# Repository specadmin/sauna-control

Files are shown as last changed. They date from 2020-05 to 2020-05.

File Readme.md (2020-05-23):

# Sauna control #

This is a control board for the sauna equipment. It includes thermostat and recycling motor control.

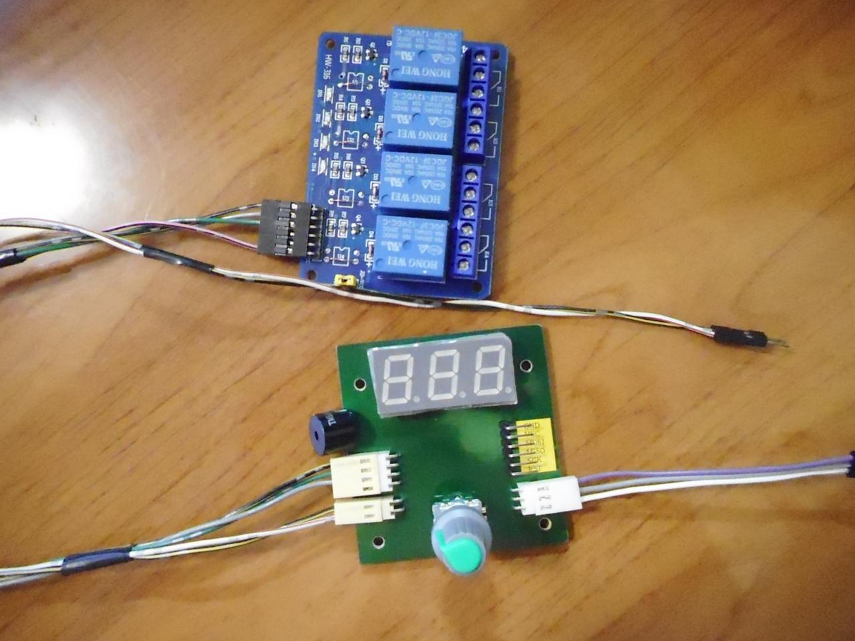
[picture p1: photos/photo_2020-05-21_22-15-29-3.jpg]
Result view


| Front side assembly | Back side assembly |
|---|---|
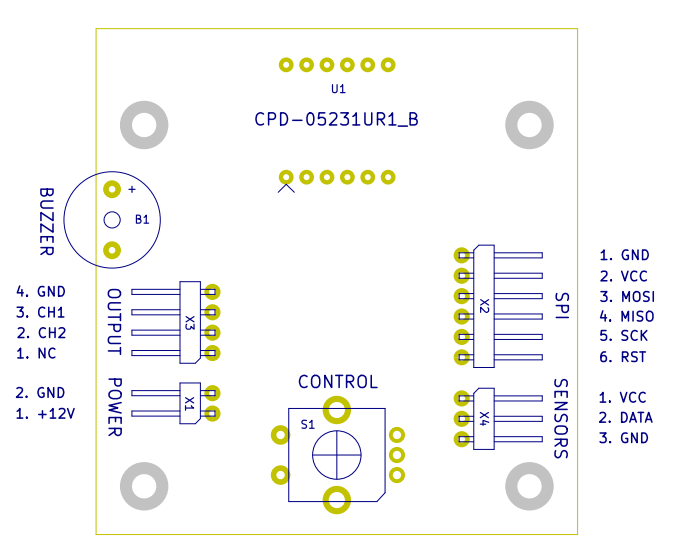
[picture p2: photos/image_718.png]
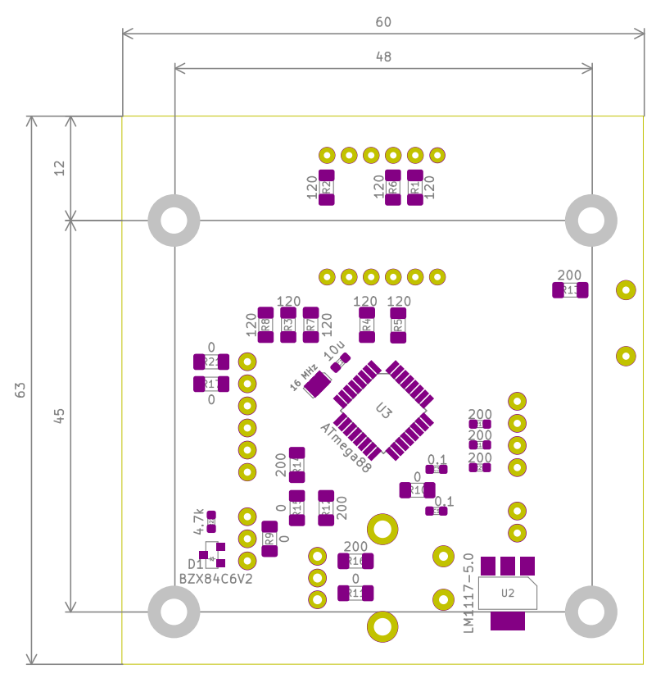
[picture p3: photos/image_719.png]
|  |  |

## Get sources ##

```
git clone https://github.com/specadmin/sauna-control
cd sauna-control
git submodule update --init
```

## Compile  ##

`make`

Make sure you have `avr-gcc` and `avr-libc` installed before running this command.

## Upload ##

`make install`

This command uses `avrdude` for uploading the firmware. See Makefile for details.

## Code modification ##

Use Code::Blocks or any other IDE for code modification.

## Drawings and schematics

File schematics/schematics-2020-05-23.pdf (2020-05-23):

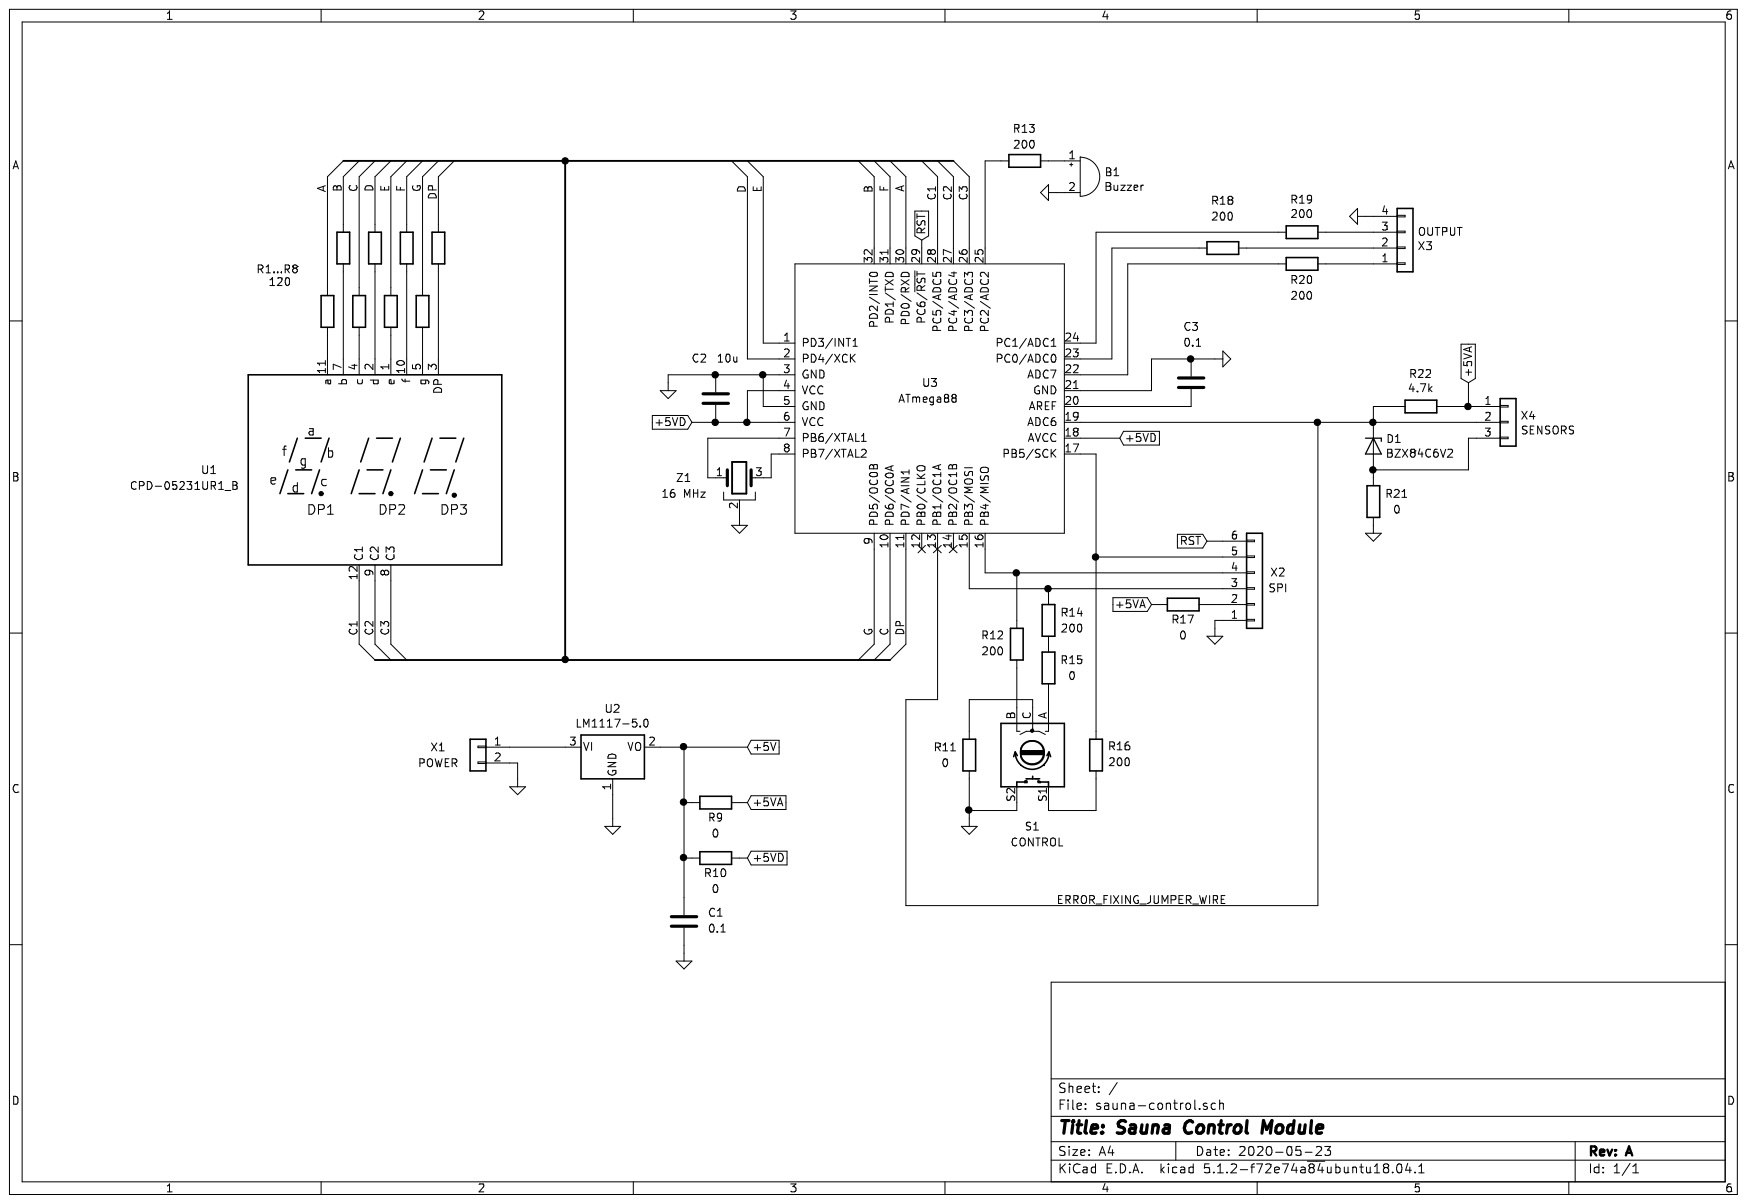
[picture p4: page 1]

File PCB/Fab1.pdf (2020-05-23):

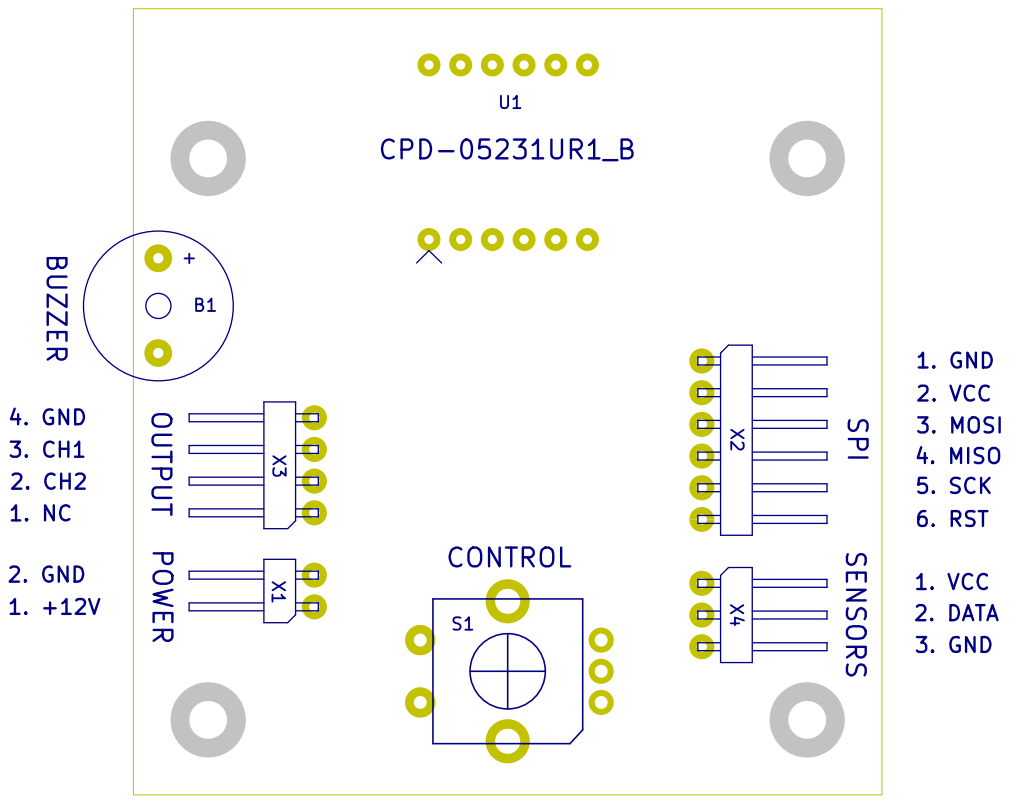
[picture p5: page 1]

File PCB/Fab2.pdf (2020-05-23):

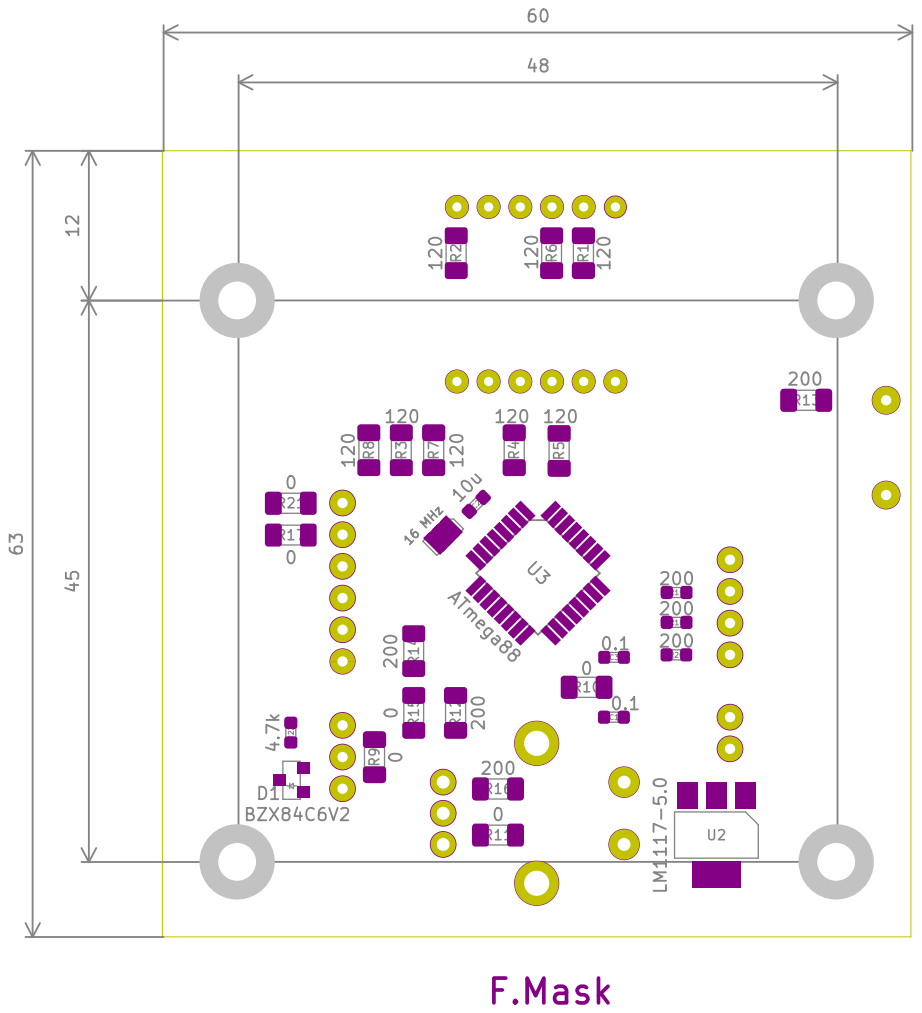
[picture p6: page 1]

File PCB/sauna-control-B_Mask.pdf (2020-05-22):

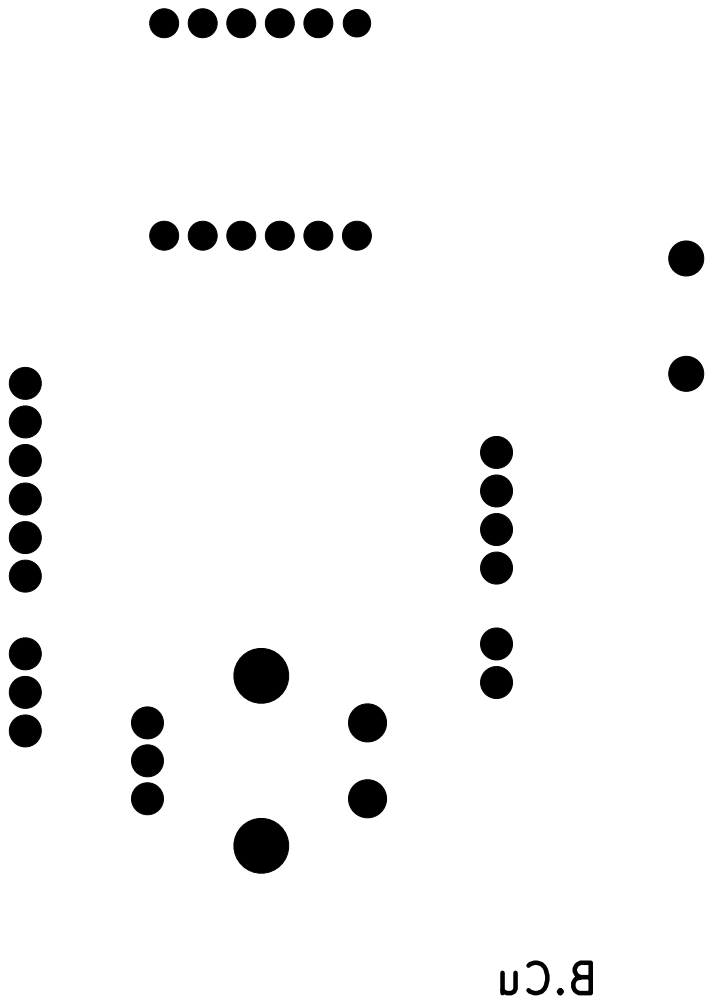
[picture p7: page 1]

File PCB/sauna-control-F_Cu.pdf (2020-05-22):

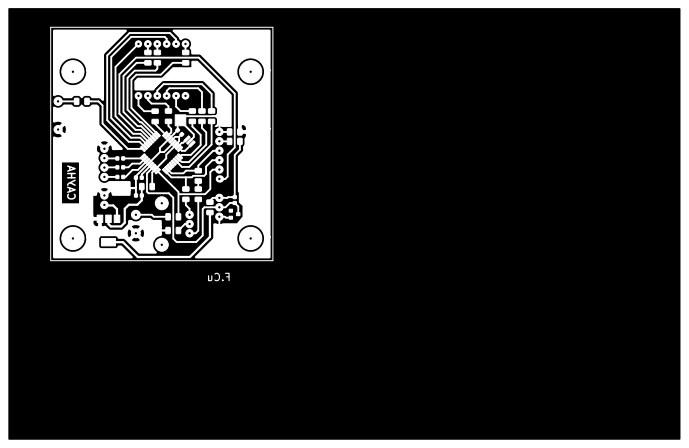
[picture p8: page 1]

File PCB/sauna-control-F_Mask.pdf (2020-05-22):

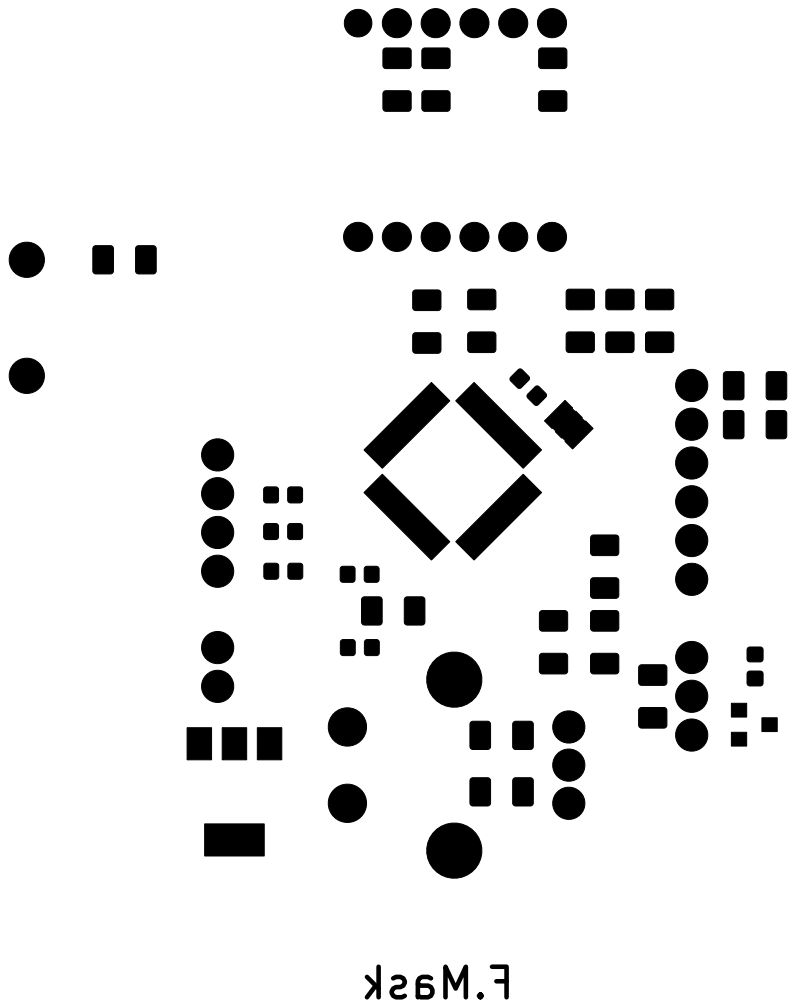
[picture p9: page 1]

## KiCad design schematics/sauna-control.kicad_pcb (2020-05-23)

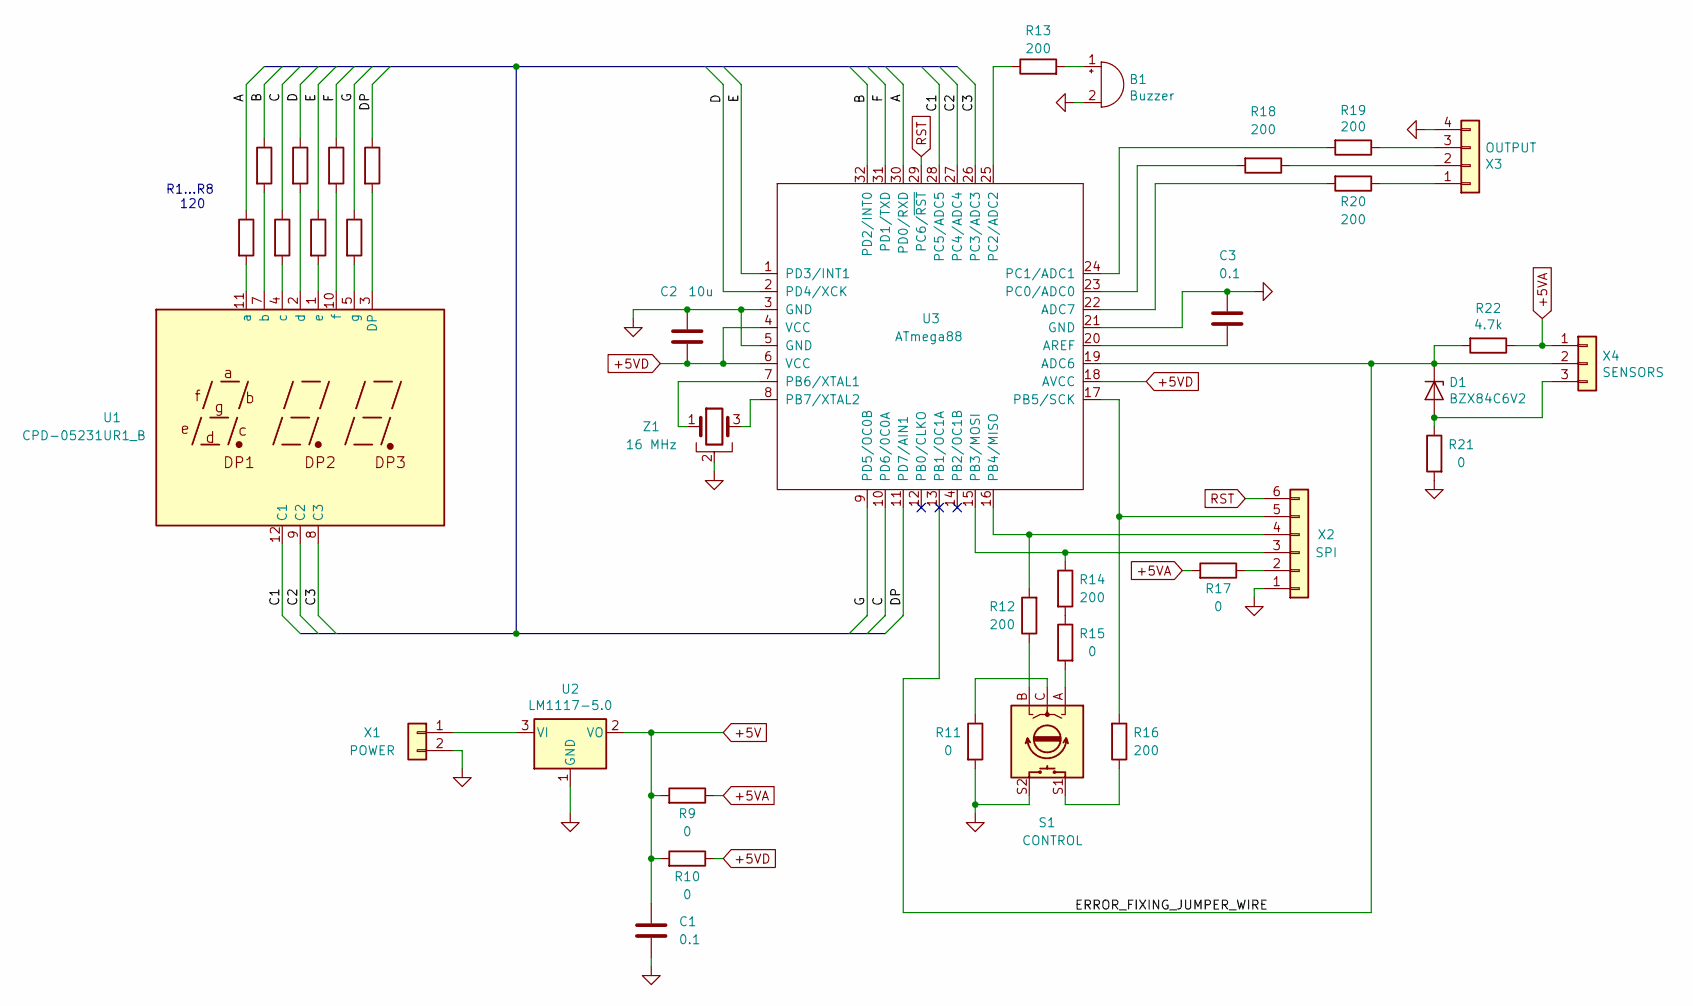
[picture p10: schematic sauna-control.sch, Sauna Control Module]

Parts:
B1: Buzzer; Buzzer_12x9.5RM7.6
C1, C3: 0.1; C_0603_1608Metric
C2: 10u; C_0603_1608Metric
D1: BZX84C6V2; D_SOT-23_ANK
R1, R2, R3, R4, R5, R6, R7, R8: 120; R_1206_3216Metric
R9, R10, R11, R15, R17, R21: 0; R_1206_3216Metric
R12, R13, R14, R16: 200; R_1206_3216Metric
R18, R19, R20: 200; R_0603_1608Metric
R22: 4.7k; R_0603_1608Metric
S1: CONTROL; RotaryEncoder_Alps_EC11E-Switch_Vertical_H20mm_CircularMoun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
U1: CPD-05231UR1_B; CPD-05231UR1B
U2: LM1117-5.0; SOT-223-3_TabPin2
U3: ATmega88; TQFP-32_7x7mm_P0.8mm
X1: POWER; PinHeader_1x02_P2.54mm_Horizontal
X2: SPI; PinHeader_1x06_P2.54mm_Horizontal
X3: OUTPUT; PinHeader_1x04_P2.54mm_Horizontal
X4: SENSORS; PinHeader_1x03_P2.54mm_Horizontal
Z1: 16 MHz; Resonator_SMD_muRata_CSTxExxV-3Pin_3.0x1.1mm

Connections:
+5V: C1.2, R9.2, R10.2, U2.2 (VO)
+5VA: R9.1, R17.2, R22.1, X4.1
+5VD: C2.1, R10.1, U3.4 (VCC), U3.6 (VCC), U3.18 (AVCC)
/A: R1.1, U3.30 (PD0/RXD)
/B: R2.1, U3.32 (PD2/INT0)
/C: R3.1, U3.10 (PD6/0C0A)
/C1: U1.12 (C1), U3.28 (PC5/ADC5)
/C2: U1.9 (C2), U3.27 (PC4/ADC4)
/C3: U1.8 (C3), U3.26 (PC3/ADC3)
/D: R4.1, U3.2 (PD4/XCK)
/DP: R8.1, U3.11 (PD7/AIN1)
/E: R5.1, U3.1 (PD3/INT1)
/ERROR_FIXING_JUMPER_WIRE: D1.1 (K), R22.2, U3.13 (PB1/OC1A), U3.19 (ADC6), X4.2
/F: R6.1, U3.31 (PD1/TXD)
/G: R7.1, U3.9 (PD5/OC0B)
GND: B1.2 (+), C1.1, C2.2, C3.2, R11.2, R21.2, S1.S2, U2.1 (GND), U3.3 (GND), U3.5 (GND), U3.21 (GND), X1.2, X2.1, X3.4, Z1.2
unnamed: B1.1 (-), R13.2
unnamed: C3.1, U3.20 (AREF)
unnamed: D1.2 (A), R21.1, X4.3
unnamed: R1.2, U1.11 (a)
unnamed: R2.2, U1.7 (b)
unnamed: R3.2, U1.4 (c)
unnamed: R4.2, U1.2 (d)
unnamed: R5.2, U1.1 (e)
unnamed: R6.2, U1.10 (f)
unnamed: R7.2, U1.5 (g)
unnamed: R8.2, U1.3 (DP)
unnamed: R11.1, S1.C
unnamed: R12.1, S1.B
unnamed: R12.2, U3.16 (PB4/MISO), X2.4
unnamed: R13.1, U3.25 (PC2/ADC2)
unnamed: R14.1, U3.15 (PB3/MOSI), X2.3
unnamed: R14.2, R15.1
unnamed: R15.2, S1.A
unnamed: R16.1, S1.S1
unnamed: R16.2, U3.17 (PB5/SCK), X2.5
unnamed: R17.1, X2.2
unnamed: R18.1, X3.2
unnamed: R18.2, U3.23 (PC0/ADC0)
unnamed: R19.1, X3.3
unnamed: R19.2, U3.24 (PC1/ADC1)
unnamed: R20.1, X3.1
unnamed: R20.2, U3.22 (ADC7)
unnamed: U2.3 (VI), X1.1
unnamed: U3.7 (PB6/XTAL1), Z1.1
unnamed: U3.8 (PB7/XTAL2), Z1.3
RST: U3.29 (PC6/~RST), X2.6

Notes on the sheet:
R1...R8 120

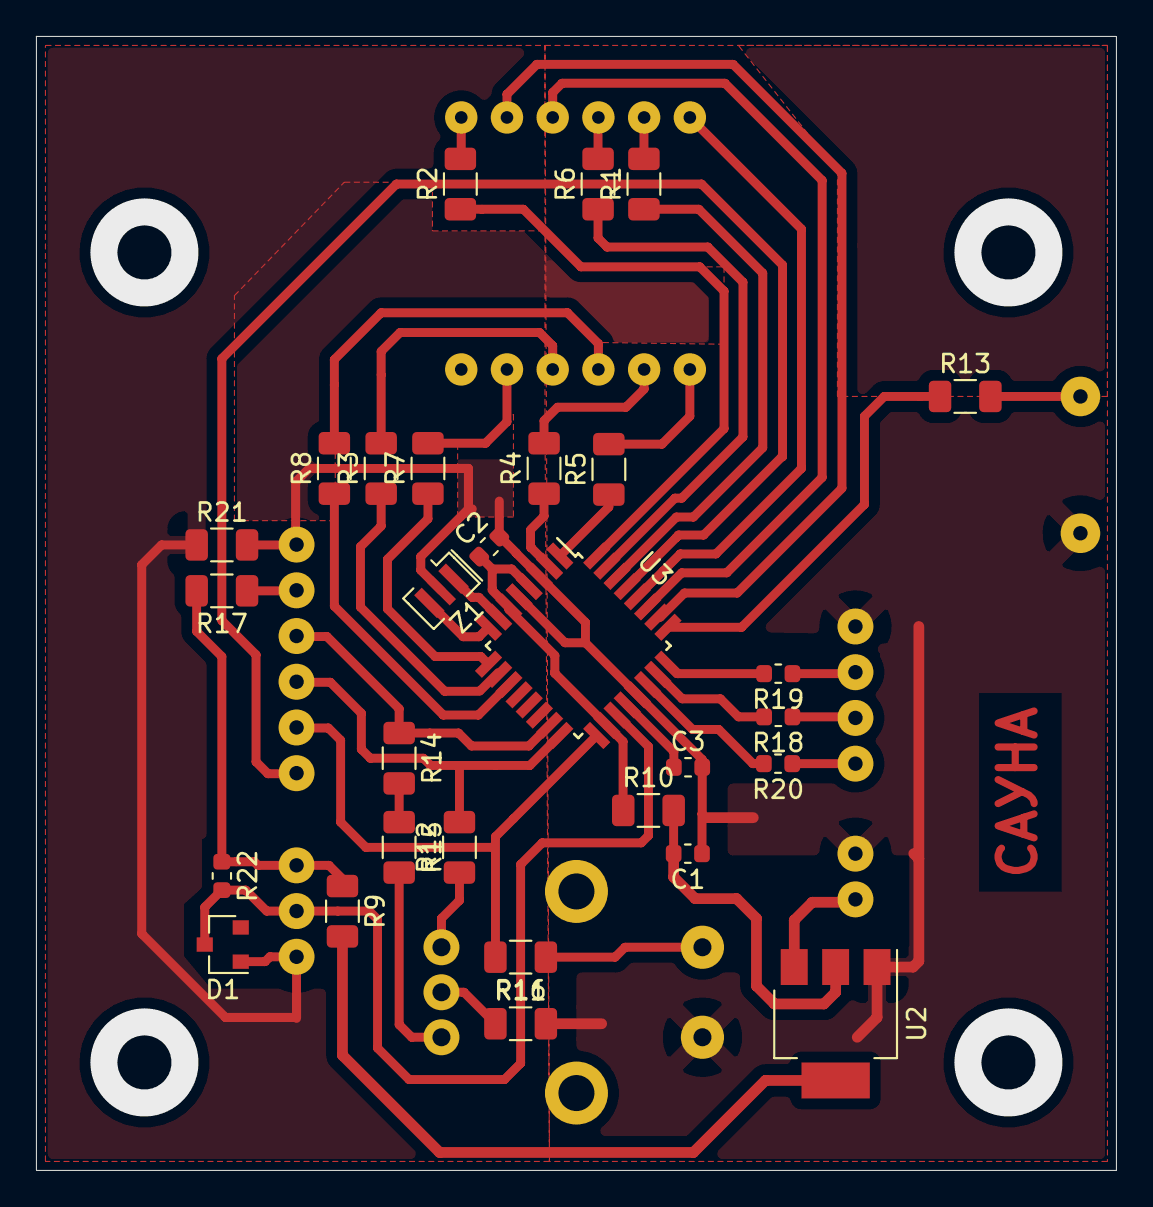
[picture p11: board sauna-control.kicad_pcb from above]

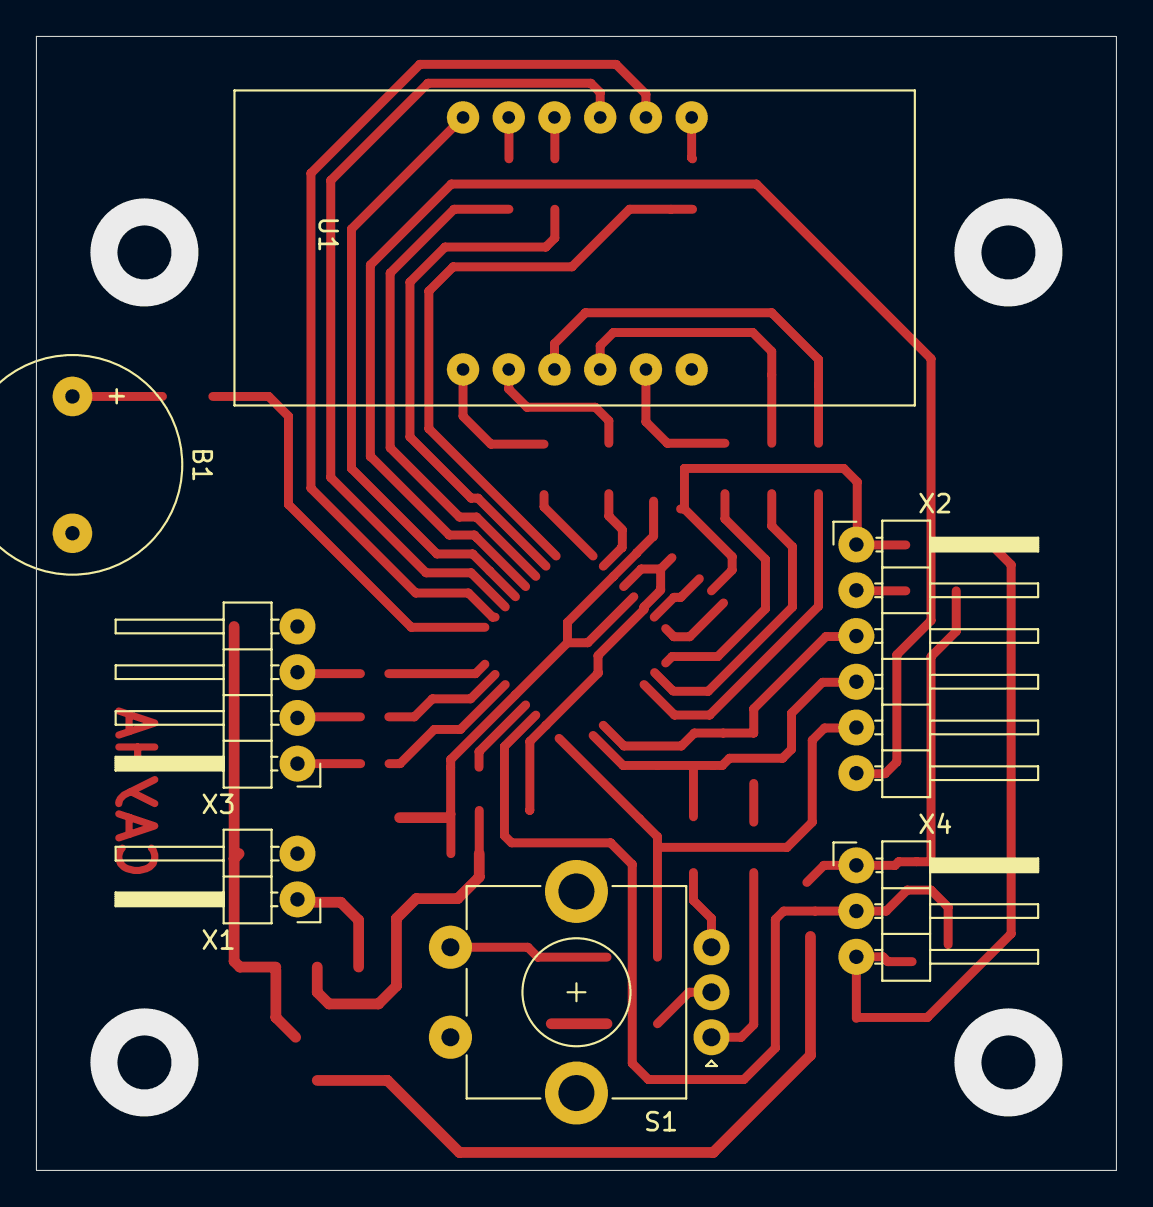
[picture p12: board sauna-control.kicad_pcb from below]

Board: 2 copper layers, 60.0 x 63.0 mm, 36 parts (7 on the bottom side), 47 nets.

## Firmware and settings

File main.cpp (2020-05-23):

//-----------------------------------------------------------------------------
#include "lib/avr-misc/avr-misc.h"
#include "lib/avr-debug/debug.h"
#include "lib/DS1820/DS1820.h"
#include "disp7seg.h"
#include "config.h"
//-----------------------------------------------------------------------------
#ifdef BEEPER_PORT
    #define beep(ms)       { set_bit(BEEPER_PORT, BEEPER_BIT); mdelay(ms); clr_bit(BEEPER_PORT, BEEPER_BIT); }
#else
    #define beep(ms)
#endif
#define enable_timer()      TCCR0B = 0x04;
#define disable_timer()     TCCR0B = 0x00;
#define enable_encoder()    set_bit(PCMSK0, PCINT3);
#define disable_encoder()   clr_bit(PCMSK0, PCINT3);
#define button_pushed()     (!test_bit(BUTTON_PIN, BUTTON_BIT))
//-----------------------------------------------------------------------------
enum
{
    MODE_SLEEP,
    MODE_SET,
    MODE_STABILIZE,
    MODE_CONFIG,
    MODE_ERROR
};
//-----------------------------------------------------------------------------
enum controlChannel
{
    HEATER,
    BLOWER
};
//-----------------------------------------------------------------------------
BYTE            mode                = MODE_SLEEP;
WORD            mode_time           = 0;
WORD            button_pushed_time  = 0;
BYTE            target_temp;
BYTE            top_temp;
BYTE            bottom_temp;
bool            bottom_sensor_enabled;
BusDS1820       bus;
SensorDS1820*   top_sensor          = NULL;
SensorDS1820*   bottom_sensor       = NULL;
Display7Seg     display(3);
EEBYTE          saved_target_temp;
EEQWORD         saved_top_address;
EEQWORD         saved_bottom_address;
//-----------------------------------------------------------------------------
void turn_on(controlChannel channel)
{
    set_bit(PORTC, channel);
}
//-----------------------------------------------------------------------------
void turn_off(controlChannel channel)
{
    clr_bit(PORTC, channel);
}
//-----------------------------------------------------------------------------
void throwError(BYTE error_code)
{
    // turn off everything
    turn_off(HEATER);
    turn_off(BLOWER);

    // display error code
    char* buf = toHexString(error_code);
    display.print(buf);
    display.hideDot();
    free(buf);

    mode = MODE_ERROR;

    // disable encoder rotations
    disable_encoder();

    // clear pending interrupts flags
    PCIFR = 1;
}
//-----------------------------------------------------------------------------
__inline BYTE init_sensors()
{
    if(!bus.searchDevices())
    {
        return 0xE1;
    }

    QWORD tmp64;
    if(!top_sensor)
    {
        tmp64 = saved_top_address;
        top_sensor = new SensorDS1820(tmp64);
    }

    if(!top_sensor->available())
    {
        return 0xE4;
    }

    tmp64 = saved_bottom_address;
    if(tmp64)
    {
        if(!bottom_sensor)
        {
            bottom_sensor = new SensorDS1820(tmp64);
        }
        bottom_sensor_enabled = true;
        if(!bottom_sensor->available())
        {
            return 0xE5;
        }
    }
    else
    {
        bottom_sensor_enabled = false;
    }

    return 0;
}
//-----------------------------------------------------------------------------
void power_on()
{
    BYTE error = init_sensors();
    if(error)
    {
        throwError(error);
    }
    else
    {
        beep(150);
        target_temp = saved_target_temp;
        if(target_temp < MIN_TEMP || target_temp > MAX_TEMP)
        {
            target_temp = MIN_TEMP;
        }
        display.print(target_temp);
        enable_encoder();
        mode = MODE_SET;
        mode_time = 0;
    }
    enable_timer();
}
//-----------------------------------------------------------------------------
void power_off()
{
    disable_timer();
    DISPLAY_PORT = 0;
    display.hideDot();
    turn_off(HEATER);
    turn_off(BLOWER);
    if(saved_target_temp != target_temp)
    {
        saved_target_temp = target_temp;
    }
    beep(300);
    mode = MODE_SLEEP;
}
//-----------------------------------------------------------------------------
void configure_sensors()
{
    mode = MODE_CONFIG;
    display.print("TOP");
    enable_timer(); mdelay(500);
    display.showDot(); mdelay(500);
    display.hideDot(); mdelay(500);
    while(bus.searchDevices() != 1)
    {
        display.showDot(); mdelay(500);
        display.hideDot(); mdelay(500);
    }
    // save top sensor address
    saved_top_address = bus.getFirstDeviceAddress();
    beep(700);

    saved_bottom_address = 0;
    display.print("BOT"); mdelay(500);
    display.showDot(); mdelay(500);
    display.hideDot(); mdelay(500);
    while(bus.searchDevices() != 2)
    {
        display.showDot(); mdelay(500);
        display.hideDot(); mdelay(500);
    }

    // save bottom sensor address
    if(bus.getFirstDeviceAddress() != saved_top_address)
    {
        saved_bottom_address = bus.getFirstDeviceAddress();
    }
    else
    {
        saved_bottom_address = bus.getNextDeviceAddress();
    }
    display.showDot(); mdelay(500);
    display.hideDot(); mdelay(500);
    beep(700);

    power_on();
}
//-----------------------------------------------------------------------------
int main()
{
    DEBUG_INIT();

    // configure ouputs
    DDRD = 0xFF;
    DDRC = 0x3F;

    // configure buttons
    set_bit(ENCODER_A_PORT, ENCODER_A_BIT);
    set_bit(ENCODER_B_PORT, ENCODER_B_BIT);
    set_bit(BUTTON_PORT, BUTTON_BIT);
    set_bit(PCIFR, PCIF0);      // clear pending interrupt flag
    set_bit(PCMSK0, PCINT5);    // enable button

    // configure timer
    TIMSK0 = 0x01;

    enable_interrupts();

#ifdef DEBUG
    //configure_sensors();
    power_on();
    PCICR = 0x00;
#else
    if(button_pushed())
    {
        configure_sensors();
    }
    PCICR = 0x01;
#endif

    while(1)
    {
        switch(mode)
        {
        case MODE_SLEEP:
            turn_off(HEATER);
            turn_off(BLOWER);
            break;
        case MODE_ERROR:
            turn_off(HEATER);
            turn_off(BLOWER);
            beep(100); mdelay(100);
            beep(100); mdelay(100);
            beep(100); mdelay(100);
            while(mode == MODE_ERROR)
            {
                mdelay(100);
            };
            break;
        case MODE_SET:
            display.print(target_temp);
            bus.allSensors.measure();
            break;
        case MODE_STABILIZE:
            // get and display current temperature
            int tmp = top_sensor->readTempC();
            if((WORD)tmp == BAD_TEMP)
            {
                throwError(0xE6);
                break;
            }
            top_temp = tmp;
            display.print(top_temp);

            // stabilize the temperature
            if(top_temp < target_temp)
            {
                turn_on(HEATER);
                display.showDot();
            }
            else
            {
                turn_off(HEATER);
                display.hideDot();
            }

            if(bottom_sensor_enabled)
            {
                // stabilize the temperature difference
                tmp = bottom_sensor->readTempC();
                if((WORD)tmp == BAD_TEMP)
                {
                    throwError(0xE7);
                    break;
                }
                if(top_temp - tmp > TEMP_DIFF)
                {
                    turn_on(BLOWER);
                }
                else
                {
                    turn_off(BLOWER);
                }
            }

            bus.allSensors.measure();
            mdelay(900);
            break;
        }
        mdelay(100);
    }
    return 0;
}
//-----------------------------------------------------------------------------
ISR(TIMER0_OVF_vect)
{
    switch(mode)
    {
    case MODE_SLEEP:
        break;
    case MODE_SET:
        if(++mode_time > 500)
        {
            // save target temp to EEPROM
            if(saved_target_temp != target_temp)
            {
                saved_target_temp = target_temp;
            }

            // change mode
            mode = MODE_STABILIZE;
        }
    case MODE_ERROR:
    case MODE_STABILIZE:
#ifndef DEBUG
        // long button hold
        if(button_pushed())
        {
            if(++button_pushed_time > 300)
            {
                power_off();
                break;
            }
        }
#endif
    case MODE_CONFIG:
        display.refresh();
    }
}
//-----------------------------------------------------------------------------
ISR(PCINT0_vect)
{
    udelay(1500);           // anti-jitter delay
    set_bit(PCIFR, PCIF0);  // clear pending interrupt flag generated by jitter

    if(test_bit(ENCODER_A_PIN, ENCODER_A_BIT) == 0 && mode != MODE_SLEEP)
    {
        // encoder driver
        if(test_bit(ENCODER_B_PIN, ENCODER_B_BIT))
        {
            // LESS rotation
            if(target_temp > MIN_TEMP)
            {
                target_temp -= TEMP_STEP;
            }
        }
        else
        {
            // MORE rotation
            if(target_temp < MAX_TEMP)
            {
                target_temp += TEMP_STEP;
            }
        }
        display.print(target_temp);
        mode = MODE_SET;
        mode_time = 0;
    }

    if(button_pushed())
    {
        if(mode == MODE_SLEEP)
        {
            power_on();
        }
    }
    else
    {
        button_pushed_time = 0;
    }
}
//-----------------------------------------------------------------------------

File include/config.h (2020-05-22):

#ifndef CONFIG_H
#define CONFIG_H
//----------------------------------------------------------------------------
#include <avr/io.h>
//----------------------------------------------------------------------------
//#define BEEPER_PORT         PORTC
#define BEEPER_BIT          2

#define ENCODER_A_PORT      PORTB
#define ENCODER_A_PIN       PINB
#define ENCODER_A_BIT       3

#define ENCODER_B_PORT      PORTB
#define ENCODER_B_PIN       PINB
#define ENCODER_B_BIT       4

#define BUTTON_PORT         PORTB
#define BUTTON_PIN          PINB
#define BUTTON_BIT          5

#define ONE_WIRE_PORT       PORTB
#define ONE_WIRE_DDR        DDRB
#define ONE_WIRE_PIN        PINB
#define ONE_WIRE_BIT        1

#define DISPLAY_PORT        PORTD

#define DEBUG_PORT          PORTB
#define DEBUG_DDR           DDRB
#define DEBUG_BIT           4
#define DEBUG_BAUD_RATE     1152000
#define DEBUG_EXTENDED_DUMP
#define RAM_GUARD_ENABLED


#define MIN_TEMP            30
#define MAX_TEMP            120
#define TEMP_STEP           1
#define TEMP_DIFF           2
//----------------------------------------------------------------------------
#endif

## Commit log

2020-05-22 First release
    [sauna-control.kicad_pcb, sauna-control.sch]
2020-05-23 Documentation improvements
    [sauna-control.kicad_pcb, sauna-control.sch]
2020-05-23 Display error code before error sound
    [main.cpp]
